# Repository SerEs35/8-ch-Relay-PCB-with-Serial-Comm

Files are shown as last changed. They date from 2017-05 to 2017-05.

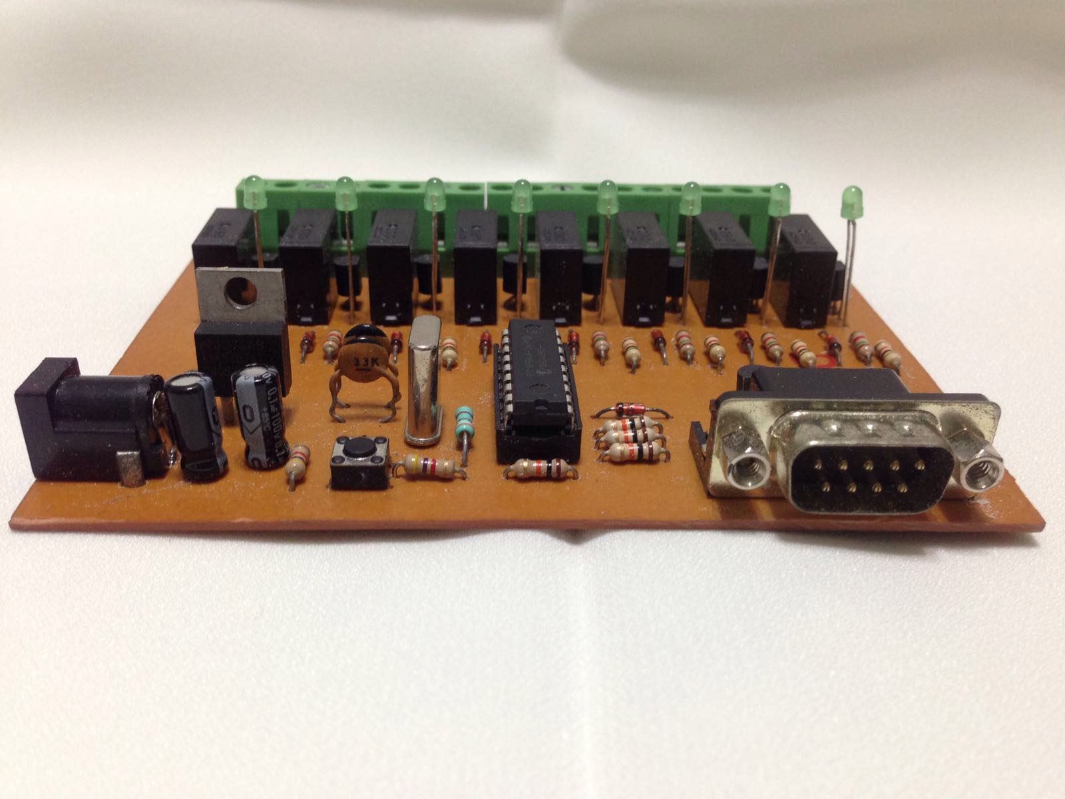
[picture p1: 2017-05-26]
IMG-20160308-WA0003.jpg

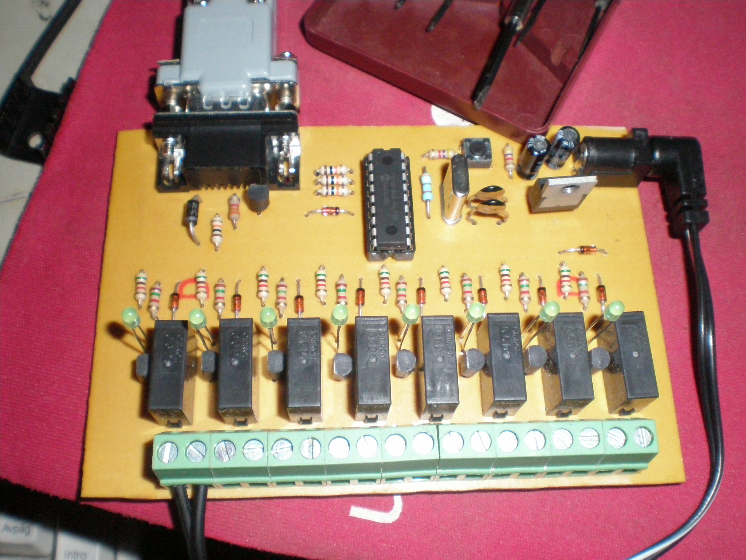
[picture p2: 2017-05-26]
P1080685.JPG

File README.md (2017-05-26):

# 8-ch-Relay-PCB-with-Serial-Comm

About this project:
----
This was a project done during undergraduate studies. It is a PCB, operated by a 16F84A microcontroller connected to the computer via Serial Port. The relays can be activated from the computer, and it is only one-way transmission.

The documents in this repository are listed as follows:

\schema_8relay.sch
>Contains the schematic of the circuit, performed in Eagle Cadsoft

\schema_8relay.brd
>Contains the layout of the circuit, performed in Eagle Cadsoft

\project.asm
>Contains the source code in ASM language for the microcontroller

\Serial_rs232.zip
>Contains the source code project for the GUI coded in C# with MS Visual Studio 2003

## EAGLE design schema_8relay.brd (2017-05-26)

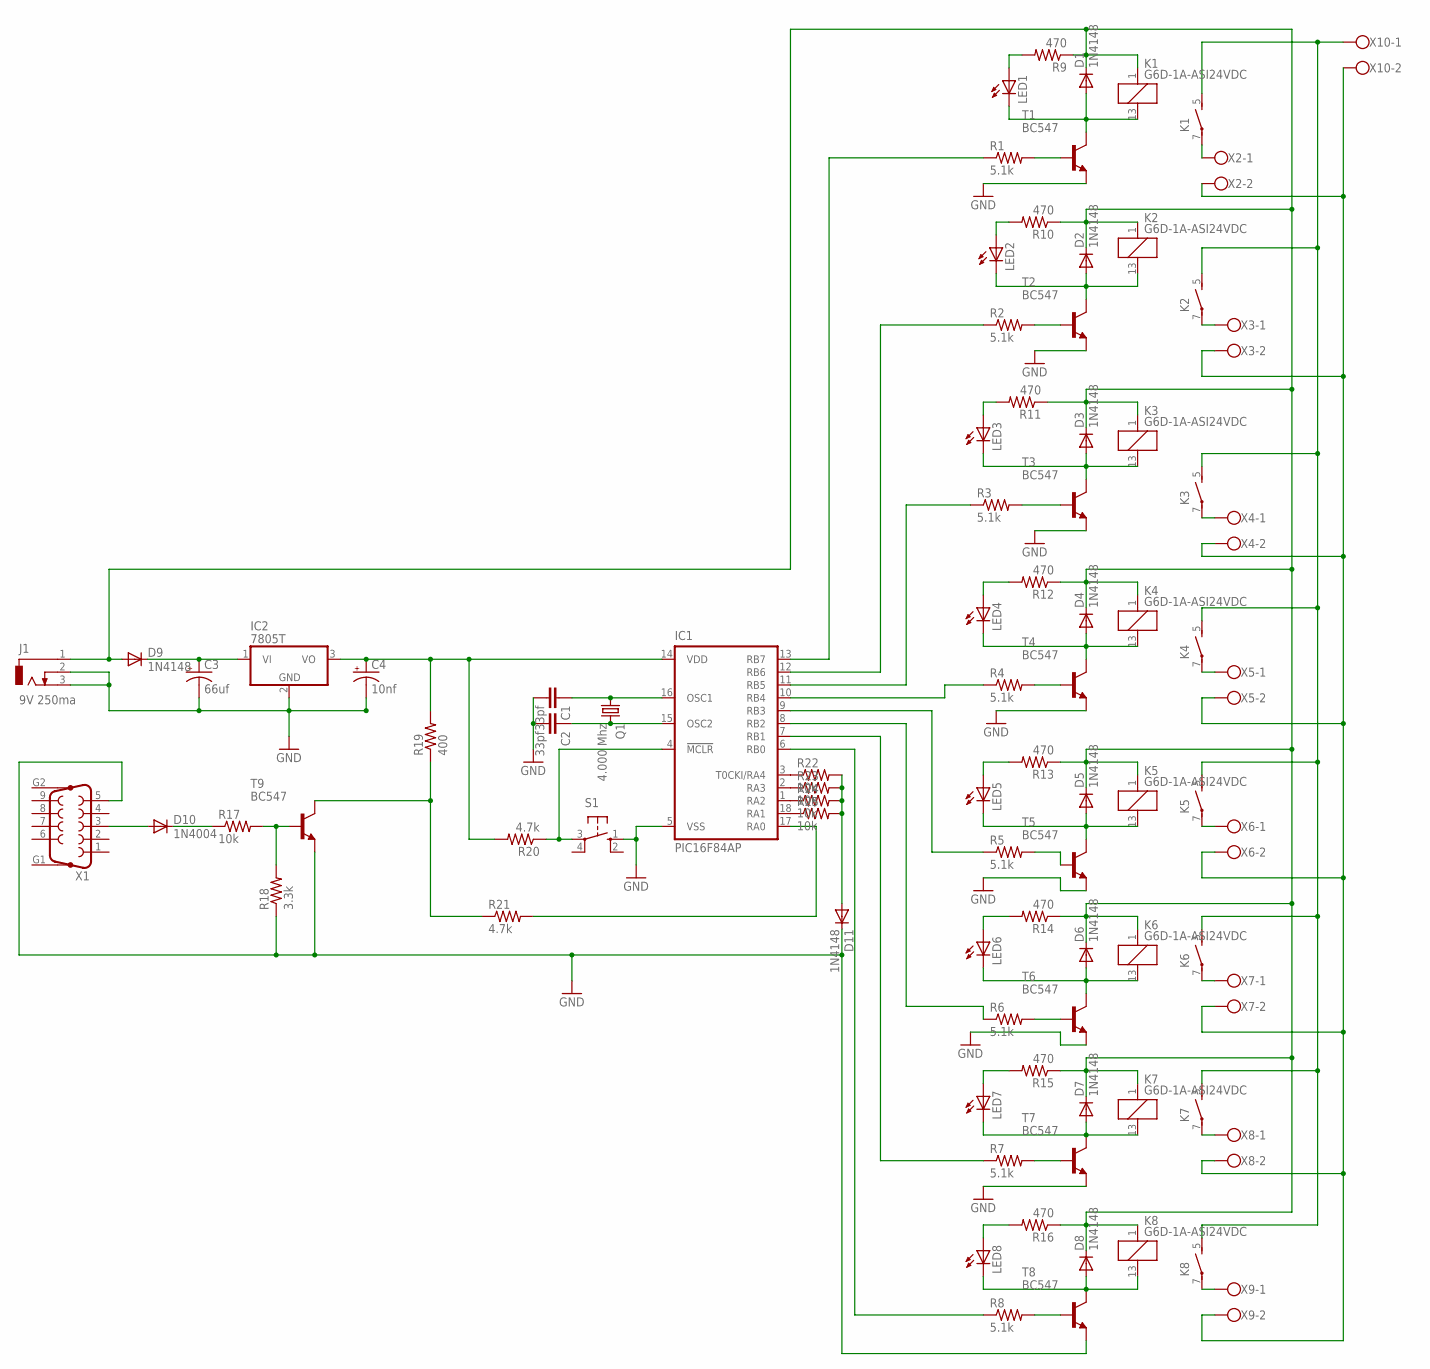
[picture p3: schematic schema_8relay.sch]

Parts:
C1, C2: 33pf; C050-024X044
C3: 66uf; E2,5-6
C4: 10nf; E2,5-6
D1, D2, D3, D4, D5, D6, D7, D8, D9, D11: 1N4148; DO35-10
D10: 1N4004; DO41-10
IC1: PIC16F84AP; DIL18
IC2: 7805T; TO220H
J1: 9V 250ma; DCJ0303
K1, K2, K3, K4, K5, K6, K7, K8: G6D-1A-ASI24VDC; G6D
LED1, LED2, LED3, LED4, LED5, LED6, LED7, LED8: LED3MM
Q1: 4.000 Mhz; HC49U70
R1, R2, R3, R4, R5, R6, R7, R8: 5.1k; 0204/7
R9, R10, R11, R12, R13, R14, R15, R16: 470; 0204/7
R17, R22, R23, R24, R25: 10k; 0204/7
R18: 3.3k; 0204/7
R19: 400; 0207/12
R20, R21: 4.7k; 0204/7
S1: 10-XX; B3F-10XX
T1, T2, T3, T4, T5, T6, T7, T8, T9: BC547; TO92
X1: F09HP
X2, X3, X4, X5, X6, X7, X8, X9, X10: W237-102

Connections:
GND: C1.2, C2.2, C3.-, C4.-, D11.C, IC1.5 (VSS), IC2.2 (GND), J1.2, J1.3, R18.1, S1.1 (S), T1.1 (E), T2.1 (E), T3.1 (E), T4.1 (E), T5.1 (E), T6.1 (E), T7.1 (E), T8.1 (E), T9.1 (E), X1.5
unnamed: C1.1, IC1.16 (OSC1), Q1.1
unnamed: C2.1, IC1.15 (OSC2), Q1.2
unnamed: R19.1, R21.1, T9.3 (C)
unnamed: D1.A, K1.13 (2), LED1.K (C), T1.3 (C)
unnamed: R1.2, T1.2 (B)
unnamed: D2.A, K2.13 (2), LED2.K (C), T2.3 (C)
unnamed: IC1.17 (RA0), R21.2
unnamed: IC1.4 (!MCLR), R20.1, S1.3
unnamed: D10.A, X1.3
unnamed: D10.C, R17.1
unnamed: R17.2, R18.2, T9.2 (B)
unnamed: C4.+, IC1.14 (VDD), IC2.3 (VO), R19.2, R20.2
unnamed: IC1.13 (RB7), R1.1
unnamed: K1.7, X2.1
unnamed: R2.2, T2.2 (B)
unnamed: LED2.A, R10.2
unnamed: D4.A, K4.13 (2), LED4.K (C), T4.3 (C)
unnamed: D6.A, K6.13 (2), LED6.K (C), T6.3 (C)
unnamed: LED4.A, R12.2
unnamed: K2.7, X3.1
unnamed: IC1.10 (RB4), R4.1
unnamed: R3.2, T3.2 (B)
unnamed: R5.2, T5.2 (B)
unnamed: LED5.A, R13.2
unnamed: K3.7, X4.1
unnamed: IC1.9 (RB3), R5.1
unnamed: R4.2, T4.2 (B)
unnamed: LED6.A, R14.2
unnamed: LED3.A, R11.2
unnamed: K4.7, X5.1
unnamed: K1.5 (S), K2.5 (S), K3.5 (S), K4.5 (S), K5.5 (S), K6.5 (S), K7.5 (S), K8.5 (S), X10.1
unnamed: C3.+, D9.C, IC2.1 (VI)
unnamed: K5.7, X6.1
unnamed: IC1.3 (T0CKI/RA4), R22.1
unnamed: R6.2, T6.2 (B)
unnamed: IC1.2 (RA3), R23.1
unnamed: K6.7, X7.1
unnamed: IC1.1 (RA2), R24.1
unnamed: R7.2, T7.2 (B)
unnamed: D7.A, K7.13 (2), LED7.K (C), T7.3 (C)
unnamed: IC1.18 (RA1), R25.1
unnamed: K7.7, X8.1
unnamed: D5.A, K5.13 (2), LED5.K (C), T5.3 (C)
unnamed: R8.2, T8.2 (B)
unnamed: LED8.A, R16.2
unnamed: LED7.A, R15.2
unnamed: K8.7, X9.1
unnamed: IC1.6 (RB0), R8.1
unnamed: IC1.7 (RB1), R7.1
unnamed: IC1.8 (RB2), R6.1
unnamed: D8.A, K8.13 (2), LED8.K (C), T8.3 (C)
unnamed: LED1.A, R9.2
unnamed: IC1.11 (RB5), R3.1
unnamed: IC1.12 (RB6), R2.1
unnamed: X2.2, X3.2, X4.2, X5.2, X6.2, X7.2, X8.2, X9.2, X10.2
unnamed: D1.C, D2.C, D3.C, D4.C, D5.C, D6.C, D7.C, D8.C, D9.A, J1.1, K1.1, K2.1, K3.1, K4.1, K5.1, K6.1, K7.1, K8.1, R9.1, R10.1, R11.1, R12.1, R13.1, R14.1, R15.1, R16.1
unnamed: D3.A, K3.13 (2), LED3.K (C), T3.3 (C)
unnamed: D11.A, R22.2, R23.2, R24.2, R25.2

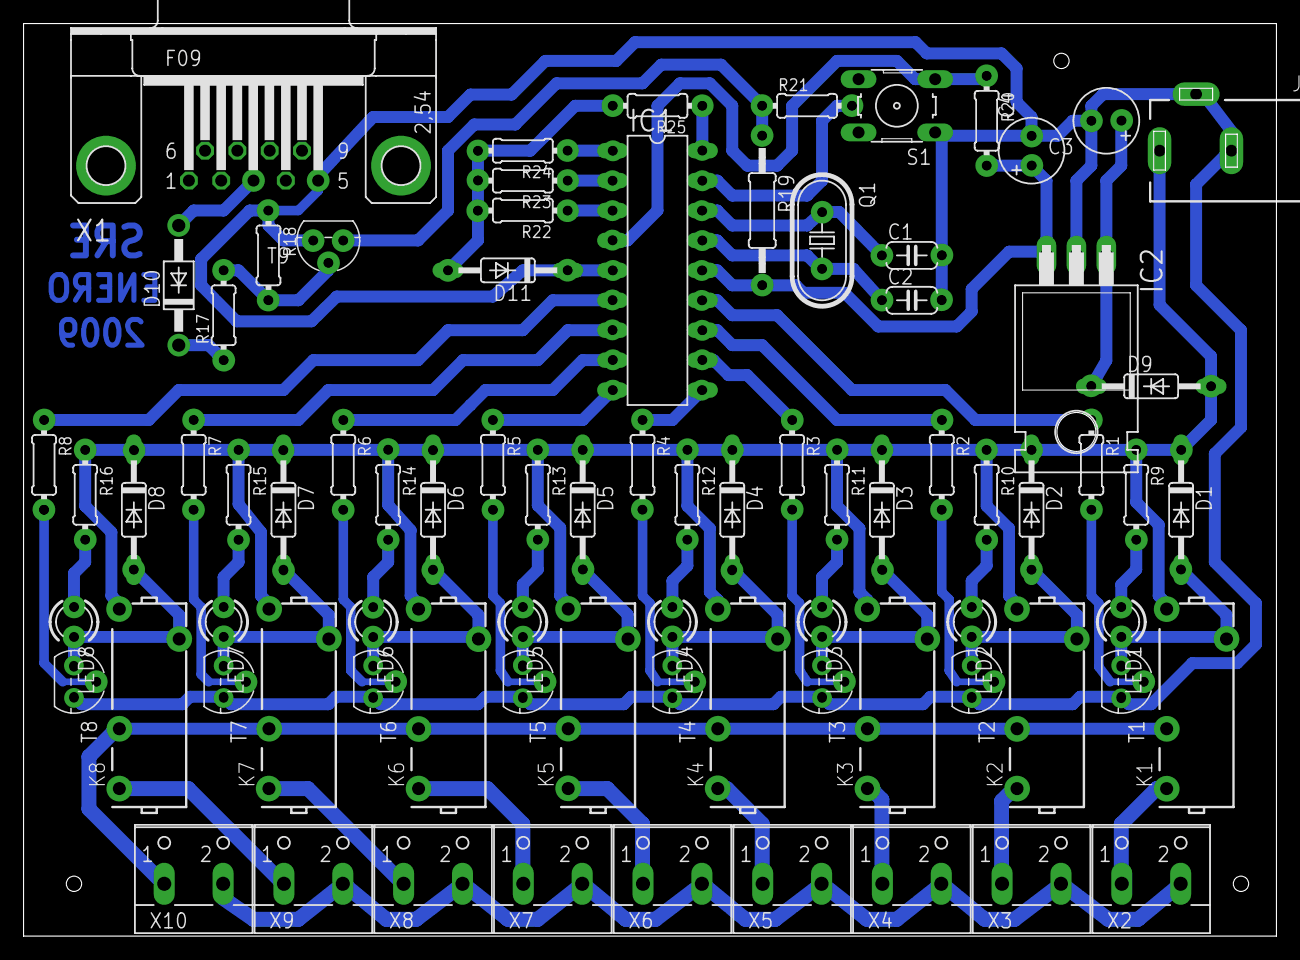
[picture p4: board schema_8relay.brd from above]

Board: 2 copper layers, 106.3 x 77.5 mm, 80 parts (0 on the bottom side), 59 nets.

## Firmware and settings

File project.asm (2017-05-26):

;--------------------------------------------------------------------------
;Author:  Sergio E.
;Name:	  Firmware for the 8-relay controller PCB
;Date:	  January, 2009
;Comment:	One-way transmission from Serial Port to Ucontroller.
;--------------------------------------------------------------------------	
	list      p=16F84A            ; list directive to define processor
	#include <p16F84A.inc>        ; processor specific variable definitions    
    
_PWRTE_ON	EQU		H'3FF7'
_XT_OSC		EQU     H'3FFD'
_WDT_OFF	EQU     H'3FFB'
_CP_OFF		EQU     H'3FFF'
;--------------------------------------------------------------------------

tmr0	equ	0x01	; Timer/counter
status	equ	0x03	; Status word reg
portA	equ	0x05	; Port A reg
portB	equ	0x06	; Port B reg
intCon	equ	0x0b	; Interrupt control reg
rcvReg	equ	0x0c	; General purpose reg
count	equ	0x0d	; General purpose reg
temp	equ	0x0e	; General purpose reg
optReg	equ	0x81	; File reg en Bank 1
trisA	equ	0x85	; File reg en Bank 1 
trisB	equ	0x86	; File reg en Bank 1 
;--------------------------------------------------------------------------

rp0	equ	5
;---------------------Start of Program-------------------------------------
	org	0x000

start	clrf	status		; Clear Status				
	bsf 	status, rp0		; To Bank 1 
	movlw	0x01			; A0 input
	movwf	trisA

	movlw	0x00			; Port B: all output
	movwf	trisB

	bcf		status, rp0		; Back to Bank 0
	clrf	portB
	clrf	rcvReg


;-------------------------------------------------------------------------	
doThis	call	rcv4800		; Yes, to serial in subroutine
	movf	rcvReg,  w		; Get byte received
	movwf	portB			; Display byte on the 8 LEDs
	
circle	goto	doThis		; Done
;--------------------------------------------------------------------------


rcv4800	bcf		intCon, 5	; Disable tmr0 interrupts
	bcf		intCon,	7		; Disable global interrupts
	clrf	tmr0			; Clear timer/counter
	;clrwdt					; Clear wdt prep prescaler assign

	bsf		status, rp0		; to Bank 1	
	;movlw	b'11011000'		; set up timer/counter
	movlw	b'11010000'		; set up timer/counter   1 instruccion cada 2 pulsos de cristal

	movwf	optReg
	bcf		status, rp0		; Back to Bank 1
	movlw	0x08			; Init shift counter
	movwf	count

;----------------------------------------------------------------------------
sbit	
	btfsc	portA, 0		; Look for start bit
	goto 	sbit			; For Mark

;---NOTA: F9 = 249 (0 a 255) . Para busqueda de fallas en synch, iterar manualmente.
;---Ver la duracion de cada instruccion, tomando en cuenta la configuracion del tiempo.

	movlw	0xEB			
	movwf	tmr0			; Load and start timer/counter
	bcf		intCon, 2		; Clear tmr0 overflow flag
	nop

time1	btfss	intCon, 2	; Has the timer (bit 2) overflowed?  Skip next line if 1
	goto	time1			; No

	btfsc	portA, 0		; Start bit still low?
	goto 	sbit			; False start, go back

	movlw	0xD2			; real, define N for timer    
	movwf	tmr0			; start timer/counter - bit time
	bcf		intCon, 2		; Clear tmr0 overflow flag
	nop

time2	btfss	intCon, 2	; Timer overflow?
	goto	time2			; No

	movf	portA, w		; Read port A
	movwf	temp			; Store
	rrf		temp, f			; Rotate bit 0 into carry flag
	rrf		rcvReg, f		; Rotate carry into rcvReg bit 7
	nop
	nop
	movlw	0xD2			; Yes, define N for timer
	movwf	tmr0			; Start timer/counter
	bcf		intCon, 2 		; Clear tmr0 overflow flag
	
	decfsz	count, f		; Shifted 8 bits from serial port?
	goto	time2			; No
	
time3	btfss	intCon, 2	; Timer overflow?
	goto	time3			; No
	return					; Yes, byte received
;-----------------------------------------------------------------------
  	end
;-----------------------------------------------------------------------
; At blast time, select:
; 	memory unprotected
; 	watchdog timer disabled
;	standard crystal (4 MHz)
; 	power-up timer on
;=======================================================================
